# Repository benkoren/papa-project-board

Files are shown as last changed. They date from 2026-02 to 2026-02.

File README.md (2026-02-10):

# papa-project-board

This is a universal controller board, centered around the ESP32-C6-DevkitC-1-N8 development board. It is meant to be a solid jumping off point for microcontroller-oriented projects which justify the beefy features of the C6 devkit, including JTAG, 32-bit RISC-V MCU & 2.4 GHz Wi-Fi 6 & Bluetooth 5 (LE) & IEEE 802.15.4, etc.

(TODO: INSERT YOUTUBE DEMO LINK)

## PCB

This universal controller board in particular includes:
 - 1.3" OLED (which you can swap for other sizes as well)
 - (2) 12mm momentary push-button switches
 - rotary encoder switch
 - active buzzer
 - (2) dedicated connectors for 3-pin sensors (ex: DHT-22)
 - (2) dedicated connectors (and extra capacitance) for driving servo motors
 - TBD62783A chip for driving things like relays while protecting our MCU
 - LM2596T-5 voltage regulator that allows the board to be driven by anywhere between 6 and 45 volts (enabling the use of a wide variety of DC power supplies)
 - 10-pin JST-XH connectors are meant to be the primary interface to the usable GPIO pins of the MCU, though extra header pins are included to facilitate tinkering on the benchtop as well
 - 4-pin JSH-XH connector used to extend the I2C devices beyond the included OLED display

For the particular components & footprints, I chose sizes that are easy to install and maintain over the long-term - all Through Hole Technology (THT) components, and no Surface Mount Device (SMD). Silkscreens were heavily utilized so that the user does not need the schematic to populate and maintain the board - all information needed is printed right on the board.

The PCB design was done in KiCad - all relevant files are located in the `KiCad` folder.

The overall approach and many schematic choices borrow a great deal from the [Banano Board by Electro Bananas](https://www.youtube.com/watch?v=pLuV-ciUMUs) - much gratitude goes to him for his work.

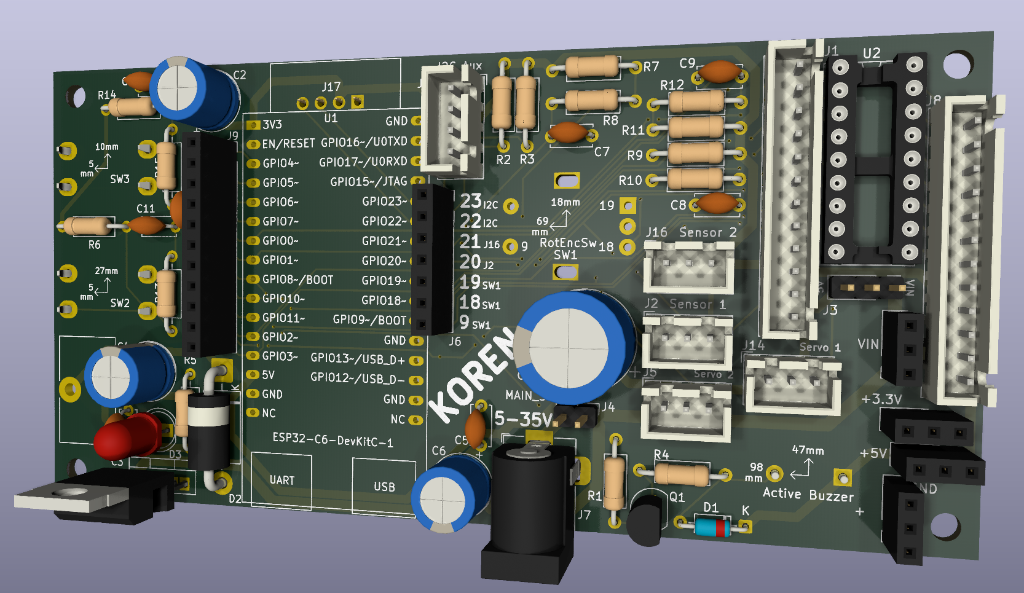
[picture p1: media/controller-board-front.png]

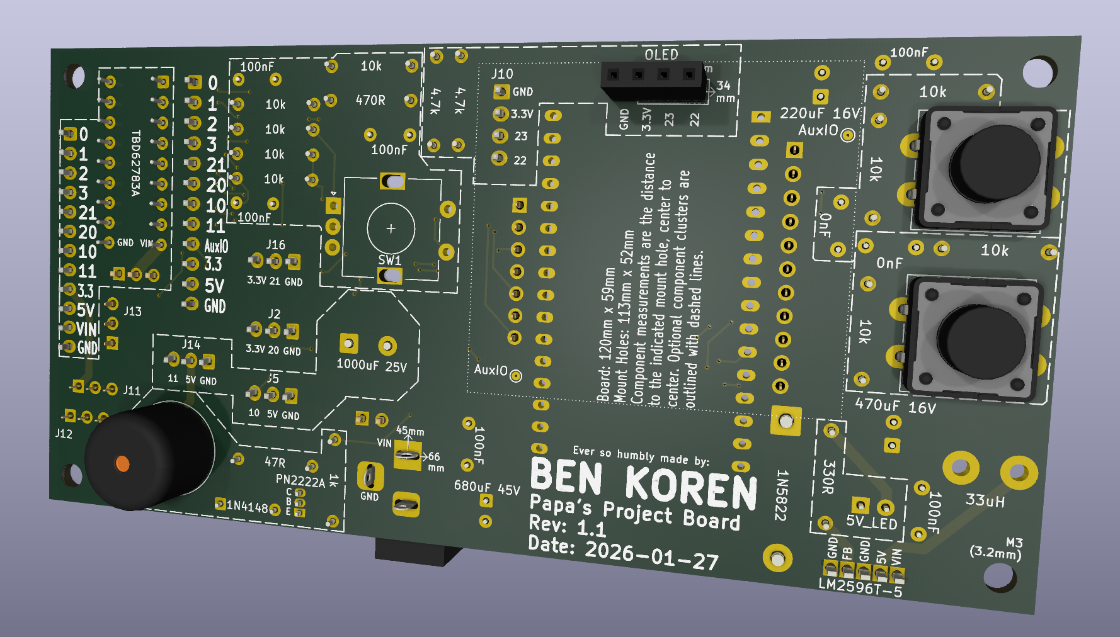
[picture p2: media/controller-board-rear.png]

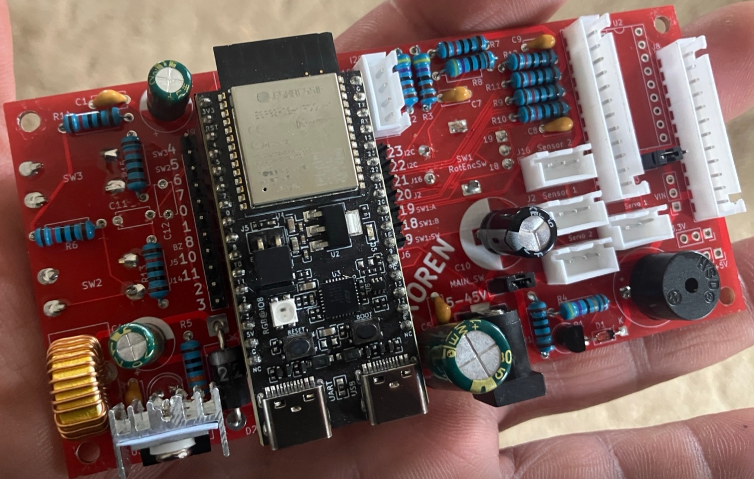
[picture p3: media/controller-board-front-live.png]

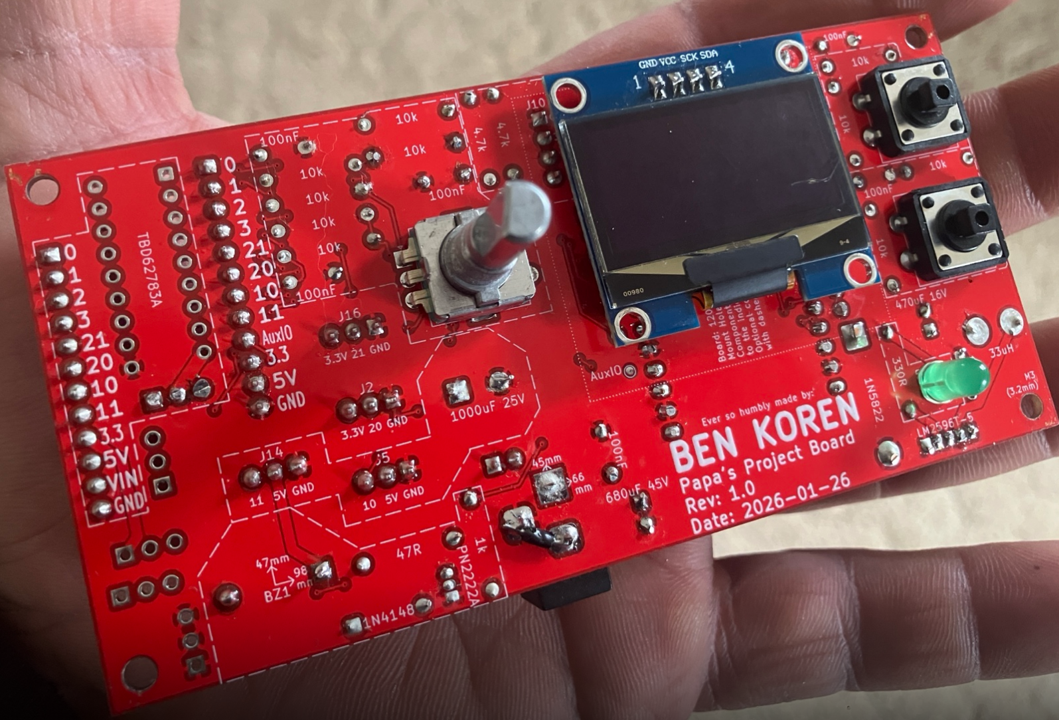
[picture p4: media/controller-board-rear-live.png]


## Enclosure

In addition to the PCB design, I've created a corresponding 3d-printed dashplate which allows the board to be incorporated into any surface mount style application.

One such application is the included "Enclosure Y", which is a small enclosure that orients the input components of the controller board up and toward the user, a rear plate where power supply and other connectors are intended to enter, and a bottom-plate which includes a 20mm grid which allows other components to be secured with included mount trays and M3 bolts.

The enclosure design was done in FreeCAD - all relevant files are located in the `FreeCAD` folder.

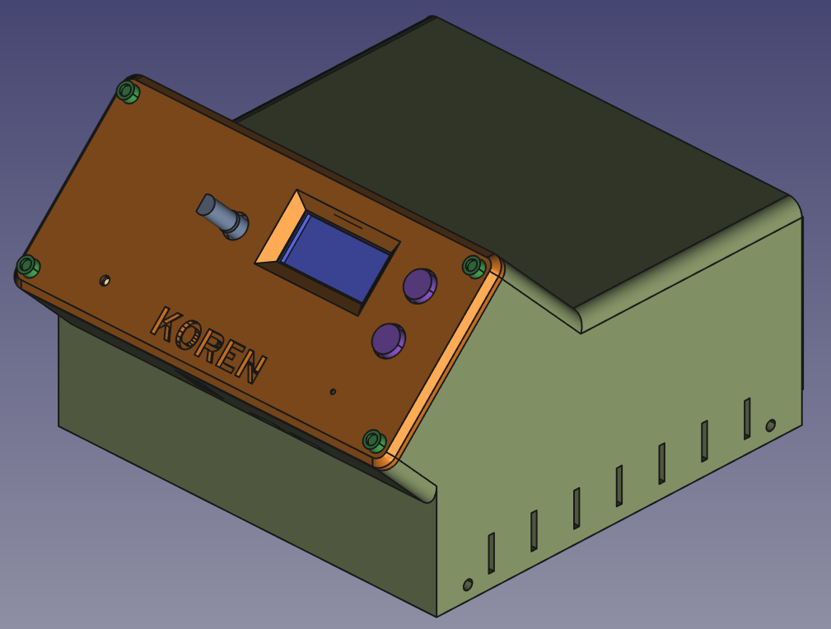
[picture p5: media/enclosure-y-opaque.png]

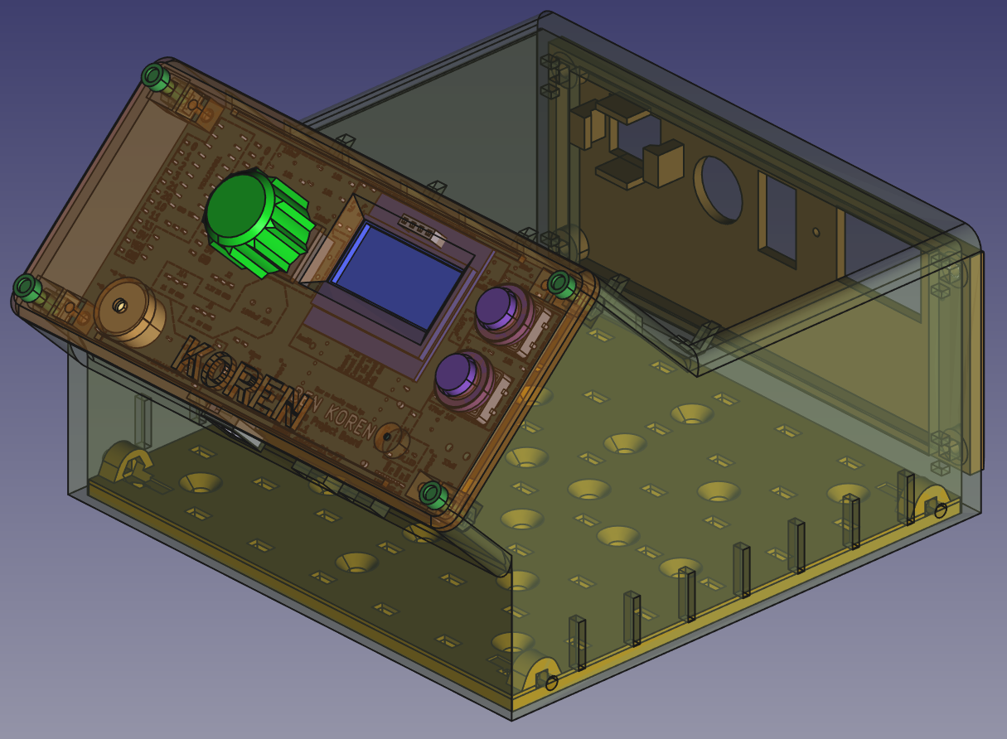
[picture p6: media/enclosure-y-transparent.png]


## Code

Perhaps just as important as the PCB itself is how it's driven: I've created a code template as a great starting point for all projects based upon the universal controller board. It supports some foundational things like driving the OLED and responding to the various inputs included with the board. It's in a separate repository here:

[Papa's Project Board - Code](https://github.com/benkoren/papa-project-board-code)

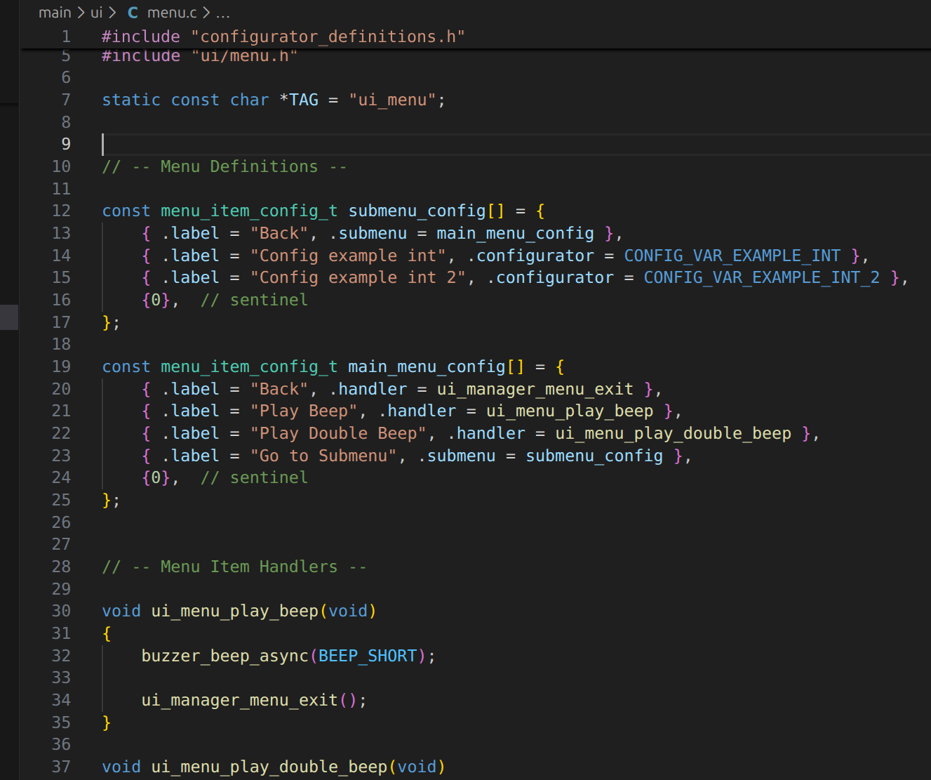
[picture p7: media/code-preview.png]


## Important Changes Across Revisions

### 1.0 to 1.1
 - C11 and C12 are now 0nF - they are counterproductive when using interrupts for SW2 and SW3. We're going to just use software debouncing instead. 
 - R8 is now 470R
 - R5 is now 4.7k (to dim the LED)
 - J7: Both pins 2 and 3 are now connected to GND

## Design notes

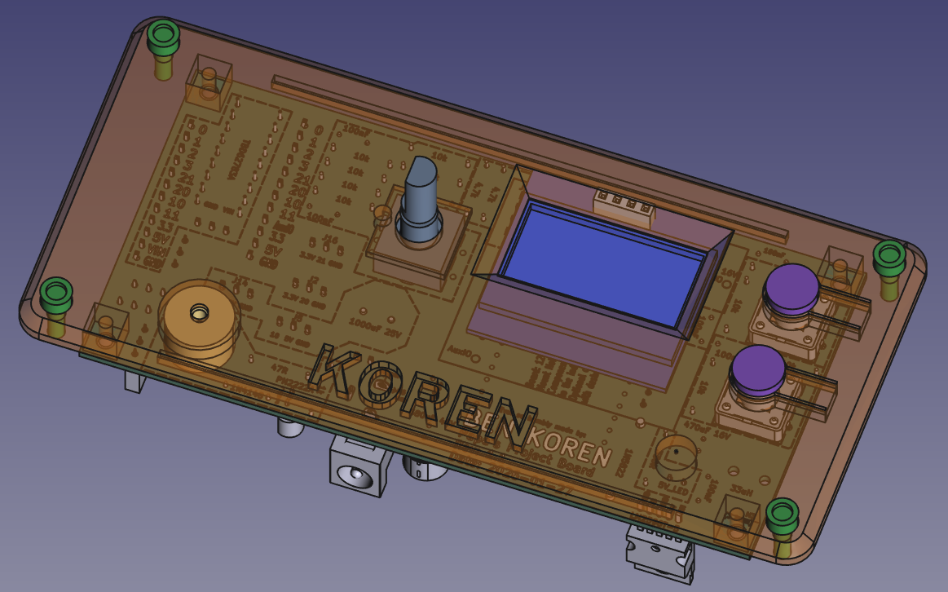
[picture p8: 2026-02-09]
media/dash-plate.png

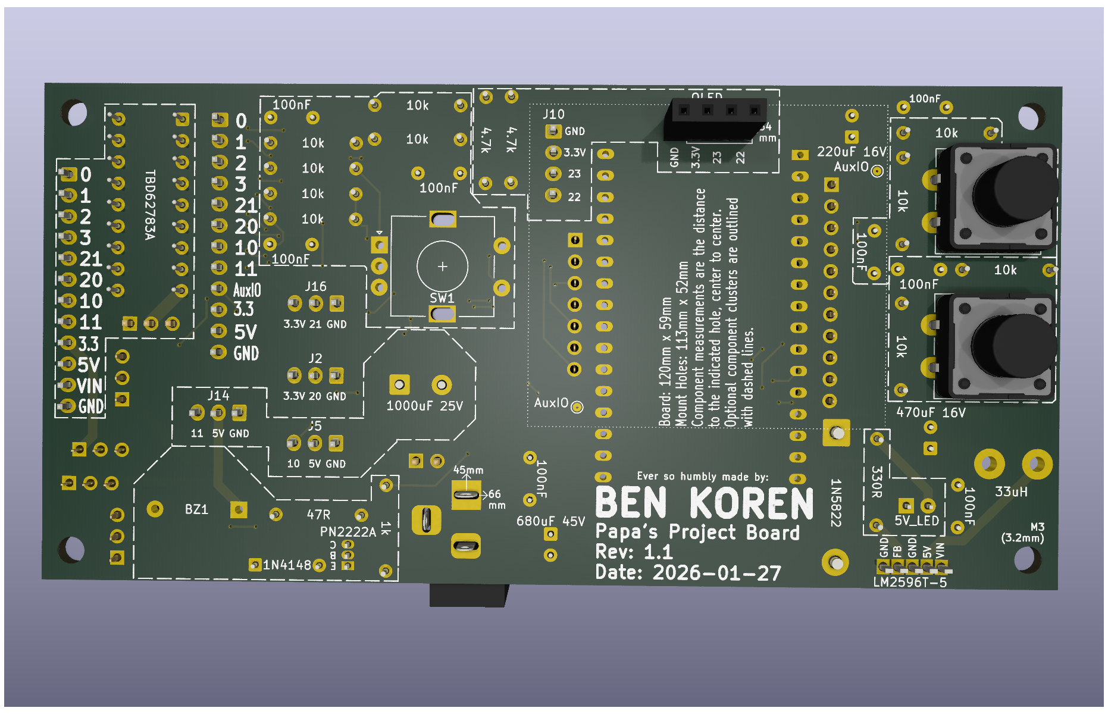
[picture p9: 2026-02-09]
KiCad/Exports/rev1.1/Rear.png

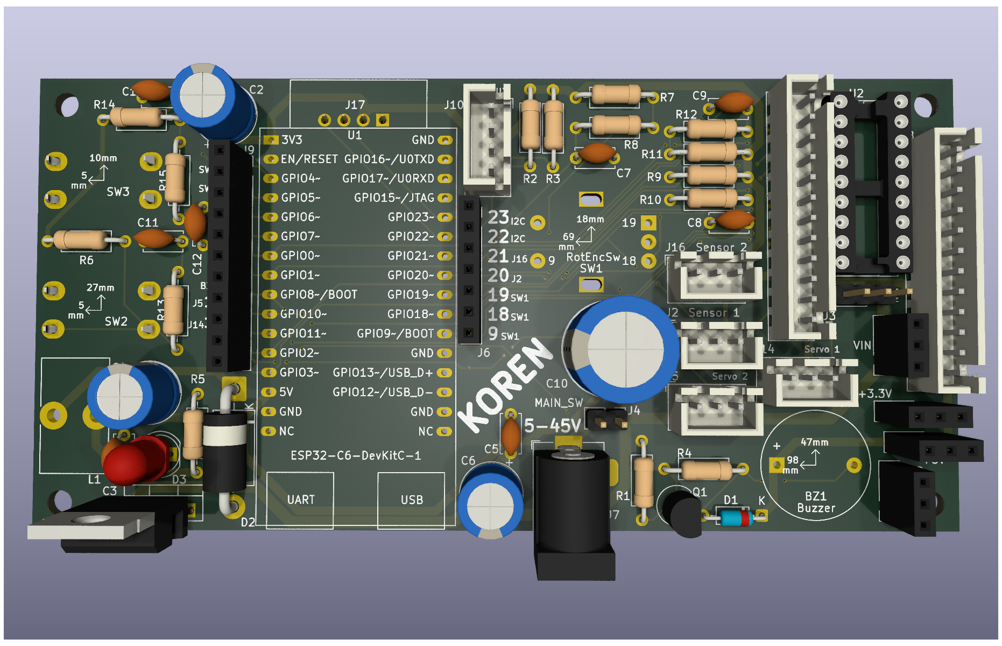
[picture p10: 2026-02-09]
KiCad/Exports/rev1.1/Front.png

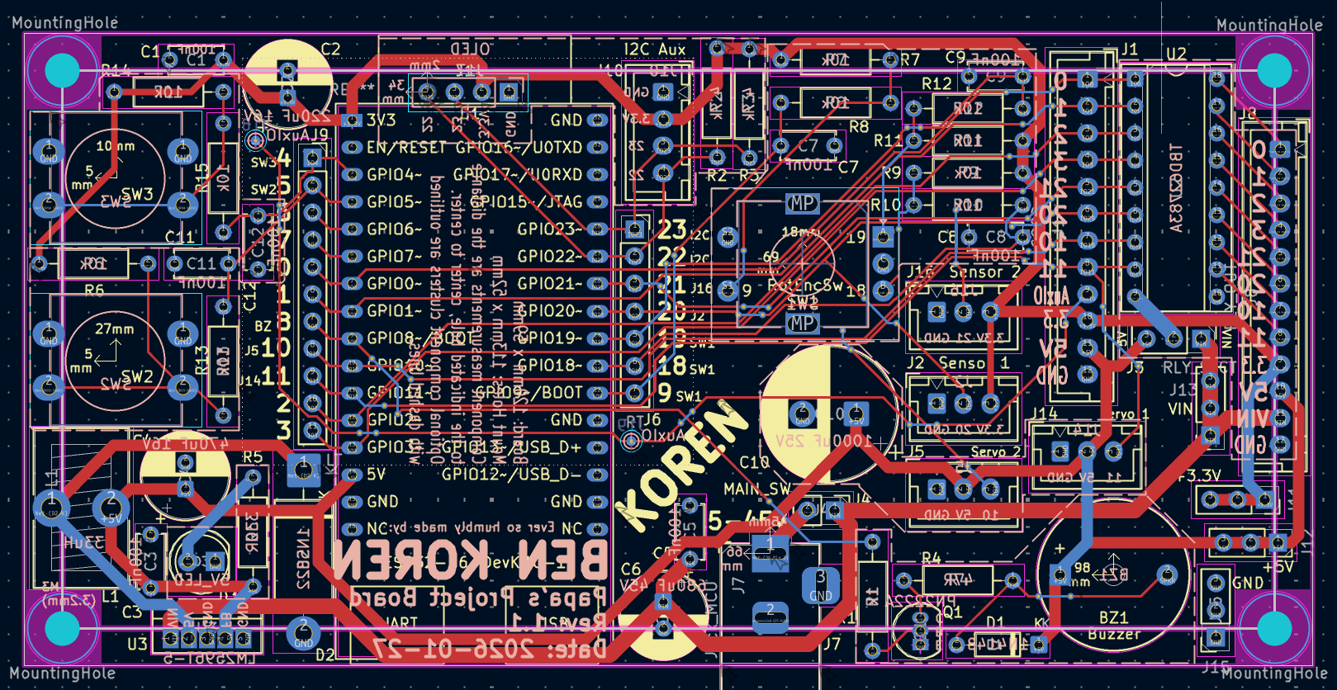
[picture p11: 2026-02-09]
KiCad/Exports/rev1.1/PCB Editor.png

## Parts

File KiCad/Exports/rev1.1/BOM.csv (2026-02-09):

Reference | Qty | Value | DNP | Exclude from BOM | Exclude from Board | Footprint | Datasheet
BZ1 | 1 | Buzzer |  |  |  | Buzzer_Beeper:Buzzer_D14mm_H7mm_P10mm | ~
C1,C3,C5,C7,C8,C9,C11,C12 | 8 | 100nF |  |  |  | Capacitor_THT:C_Disc_D5.0mm_W2.5mm_P5.00mm | ~
C2 | 1 | 220uF 16V |  |  |  | Capacitor_THT:CP_Radial_D8.0mm_P2.50mm | ~
C4 | 1 | 470uF 16V |  |  |  | Capacitor_THT:CP_Radial_D8.0mm_P2.50mm | ~
C6 | 1 | 680uF 45V |  |  |  | Capacitor_THT:CP_Radial_D8.0mm_P2.50mm | ~
C10 | 1 | 1000uF 25V |  |  |  | Capacitor_THT:CP_Radial_D12.5mm_P5.00mm | ~
D1 | 1 | 1N4148 |  |  |  | Diode_THT:D_DO-35_SOD27_P7.62mm_Horizontal | https://assets.nexperia.com/documents/data-sheet/1N4148_1N4448.pdf
D2 | 1 | 1N5822 |  |  |  | Diode_THT:D_DO-201AD_P15.24mm_Horizontal | http://www.vishay.com/docs/88526/1n5820.pdf
D3 | 1 | 5V_LED |  |  |  | LED_THT:LED_D5.0mm | ~
H1,H2,H3,H4 | 4 | MountingHole |  | Excluded from BOM |  | MountingHole:MountingHole_3.2mm_M3 | ~
J1 | 1 | GOOD |  |  |  | Connector_JST:JST_XH_B12B-XH-A_1x12_P2.50mm_Vertical | ~
J2 | 1 | Sensor 1 |  |  |  | Connector_JST:JST_XH_B3B-XH-A_1x03_P2.50mm_Vertical | ~
J3 | 1 | RLY_SLCT |  |  |  | Connector_PinHeader_2.54mm:PinHeader_1x03_P2.54mm_Vertical | ~
J4 | 1 | MAIN_SW |  |  |  | Connector_PinHeader_2.54mm:PinHeader_1x02_P2.54mm_Vertical | ~
J5 | 1 | Servo 2 |  |  |  | Connector_JST:JST_XH_B3B-XH-A_1x03_P2.50mm_Vertical | ~
J6 | 1 | RT |  |  |  | Connector_PinSocket_2.54mm:PinSocket_1x07_P2.54mm_Vertical | ~
J7 | 1 | Jack_MCU |  |  |  | Connector_BarrelJack:BarrelJack_Horizontal | ~
J8 | 1 | RLY_OUT |  |  |  | Connector_JST:JST_XH_B12B-XH-A_1x12_P2.50mm_Vertical | ~
J9 | 1 | LT |  |  |  | Connector_PinSocket_2.54mm:PinSocket_1x11_P2.54mm_Vertical | ~
J10 | 1 | I2C Aux |  |  |  | Connector_JST:JST_XH_B4B-XH-A_1x04_P2.50mm_Vertical | ~
J11 | 1 | +3.3V |  |  |  | Connector_PinSocket_2.54mm:PinSocket_1x03_P2.54mm_Vertical | ~
J12 | 1 | +5V |  |  |  | Connector_PinSocket_2.54mm:PinSocket_1x03_P2.54mm_Vertical | ~
J13 | 1 | VIN |  |  |  | Connector_PinSocket_2.54mm:PinSocket_1x03_P2.54mm_Vertical | ~
J14 | 1 | Servo 1 |  |  |  | Connector_JST:JST_XH_B3B-XH-A_1x03_P2.50mm_Vertical | ~
J15 | 1 | GND |  |  |  | Connector_PinSocket_2.54mm:PinSocket_1x03_P2.54mm_Vertical | ~
J16 | 1 | Sensor 2 |  |  |  | Connector_JST:JST_XH_B3B-XH-A_1x03_P2.50mm_Vertical | ~
J17 | 1 | OLED |  |  |  | Connector_PinSocket_2.54mm:PinSocket_1x04_P2.54mm_Vertical | ~
J18,J19 | 2 | AuxIO |  |  |  | TestPoint:TestPoint_Pad_D1.0mm | ~
L1 | 1 | 33uH |  |  |  | Inductor_THT:L_Toroid_Vertical_L14.7mm_W8.6mm_P5.58mm_Pulse_KM-1 | ~
Q1 | 1 | PN2222A |  |  |  | Package_TO_SOT_THT:TO-92_Inline | https://www.onsemi.com/pub/Collateral/PN2222-D.PDF
R1 | 1 | 1k |  |  |  | Resistor_THT:R_Axial_DIN0207_L6.3mm_D2.5mm_P10.16mm_Horizontal | ~
R2,R3 | 2 | 4.7k |  |  |  | Resistor_THT:R_Axial_DIN0207_L6.3mm_D2.5mm_P10.16mm_Horizontal | ~
R4 | 1 | 47R |  |  |  | Resistor_THT:R_Axial_DIN0207_L6.3mm_D2.5mm_P10.16mm_Horizontal | ~
R5 | 1 | 330R |  |  |  | Resistor_THT:R_Axial_DIN0207_L6.3mm_D2.5mm_P10.16mm_Horizontal | ~
R6,R7,R8,R9,R10,R11,R12,R13,R14,R15 | 10 | 10k |  |  |  | Resistor_THT:R_Axial_DIN0207_L6.3mm_D2.5mm_P10.16mm_Horizontal | ~
SW1 | 1 | RotEncSw |  |  |  | Rotary_Encoder:RotaryEncoder_Alps_EC11E-Switch_Vertical_H20mm | ~
SW2 | 1 | SW_IO5 |  |  |  | Button_Switch_THT:SW_PUSH-12mm_Wuerth-430476085716 | ~
SW3 | 1 | SW_IO8 |  |  |  | Button_Switch_THT:SW_PUSH-12mm_Wuerth-430476085716 | ~
U1 | 1 | ESP32-C6-DevKitC-1 |  |  |  | PCM_Espressif:ESP32-C6-DevKitC-1 | https://docs.espressif.com/projects/espressif-esp-dev-kits/en/latest/esp32c6/esp32-c6-devkitc-1/user_guide.html
U2 | 1 | TBD62783A |  |  |  | Package_DIP:DIP-18_W7.62mm_Socket | http://toshiba.semicon-storage.com/info/docget.jsp?did=30523&prodName=TBD62783APG
U3 | 1 | LM2596T-5 |  |  |  | Package_TO_SOT_THT:TO-220-5_Vertical | http://www.ti.com/lit/ds/symlink/lm2596.pdf

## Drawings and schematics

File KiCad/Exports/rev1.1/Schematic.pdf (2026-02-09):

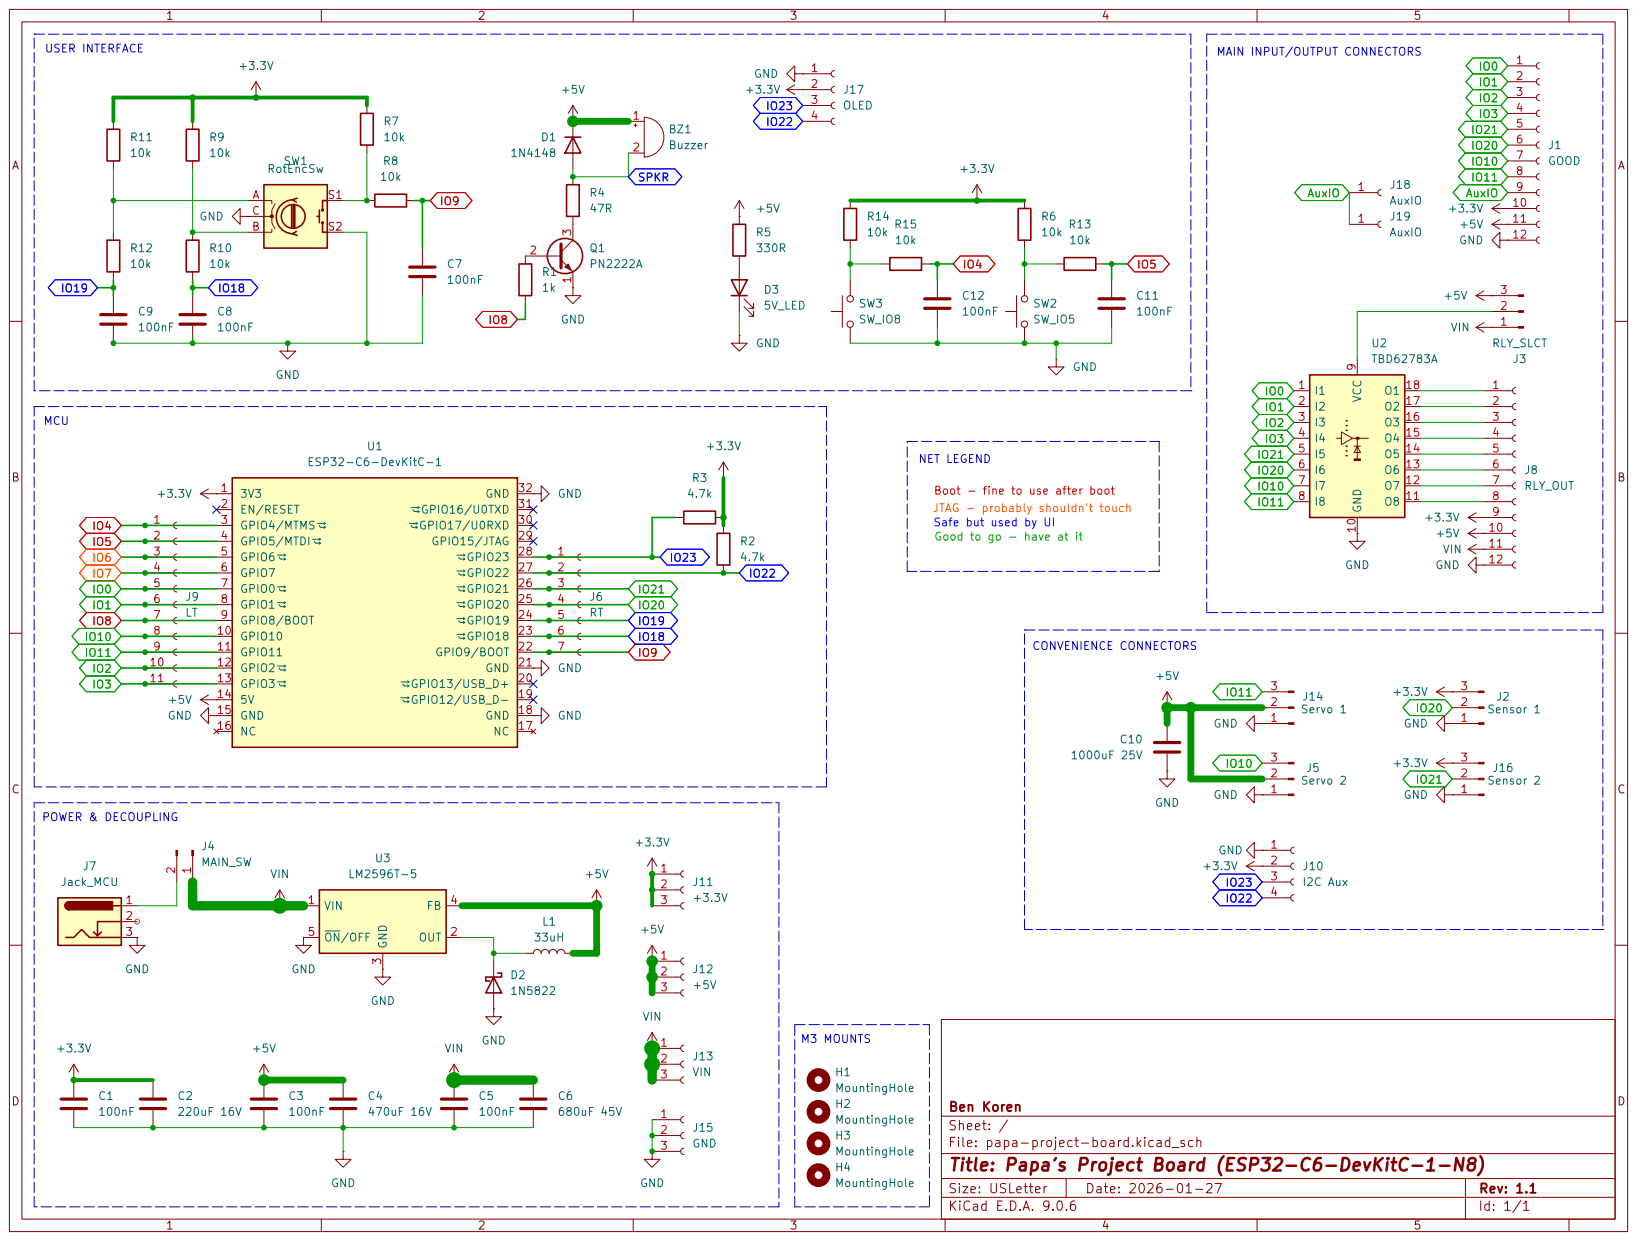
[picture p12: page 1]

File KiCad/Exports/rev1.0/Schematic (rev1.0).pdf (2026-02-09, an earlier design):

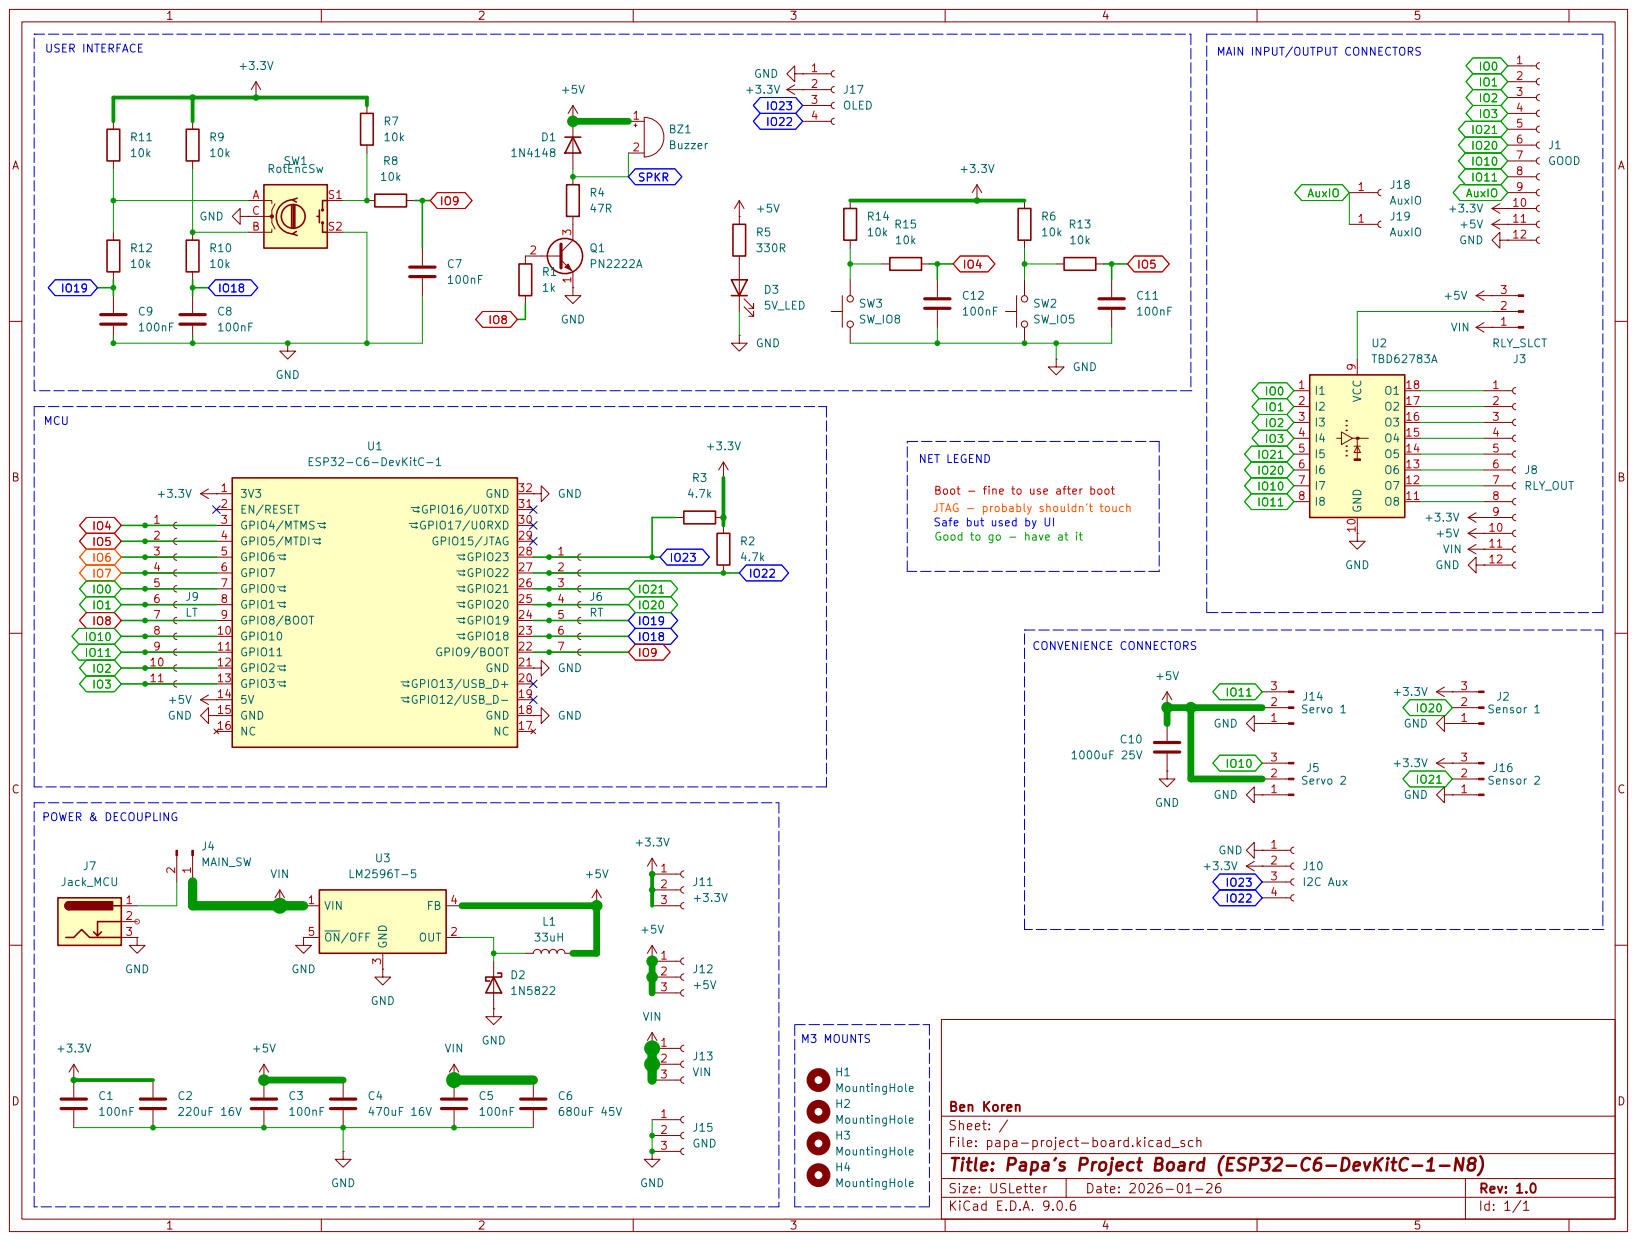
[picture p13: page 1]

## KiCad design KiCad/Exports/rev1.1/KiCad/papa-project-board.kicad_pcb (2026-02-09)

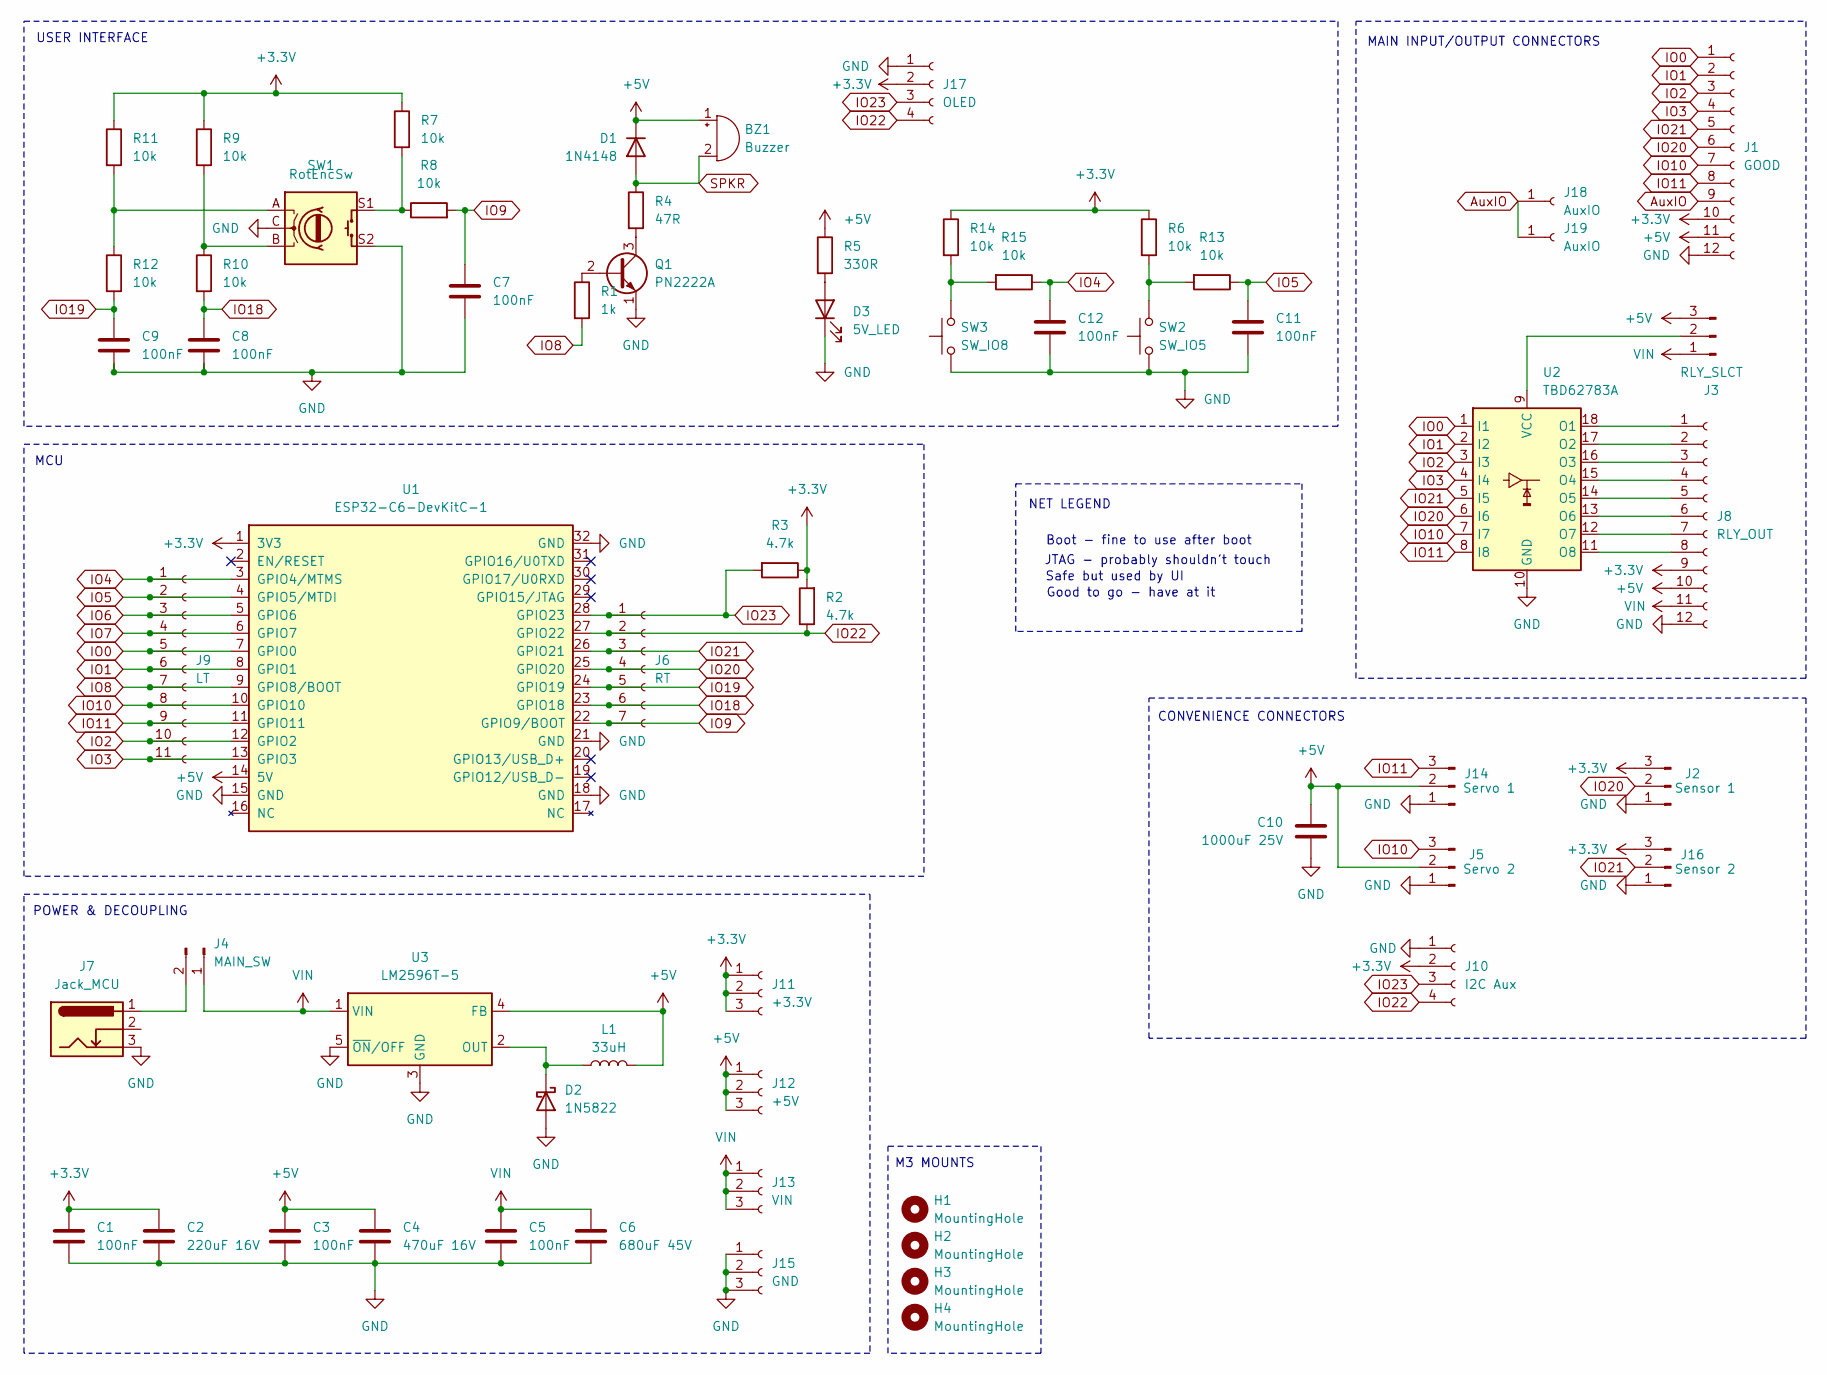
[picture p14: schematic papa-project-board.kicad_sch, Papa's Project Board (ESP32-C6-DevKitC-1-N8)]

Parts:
BZ1: Buzzer; Buzzer_D14mm_H7mm_P10mm
C1, C3, C5, C7, C8, C9, C11, C12: 100nF; C_Disc_D5.0mm_W2.5mm_P5.00mm
C2: 220uF 16V; CP_Radial_D8.0mm_P2.50mm
C4: 470uF 16V; CP_Radial_D8.0mm_P2.50mm
C6: 680uF 45V; CP_Radial_D8.0mm_P2.50mm
C10: 1000uF 25V; CP_Radial_D12.5mm_P5.00mm
D1: 1N4148; D_DO-35_SOD27_P7.62mm_Horizontal
D2: 1N5822; D_DO-201AD_P15.24mm_Horizontal
D3: 5V_LED; LED_D5.0mm
H1, H2, H3, H4: MountingHole; MountingHole_3.2mm_M3
J1: GOOD; JST_XH_B12B-XH-A_1x12_P2.50mm_Vertical
J2: Sensor 1; JST_XH_B3B-XH-A_1x03_P2.50mm_Vertical
J3: RLY_SLCT; PinHeader_1x03_P2.54mm_Vertical
J4: MAIN_SW; PinHeader_1x02_P2.54mm_Vertical
J5: Servo 2; JST_XH_B3B-XH-A_1x03_P2.50mm_Vertical
J6: RT; PinSocket_1x07_P2.54mm_Vertical
J7: Jack_MCU; BarrelJack_Horizontal
J8: RLY_OUT; JST_XH_B12B-XH-A_1x12_P2.50mm_Vertical
J9: LT; PinSocket_1x11_P2.54mm_Vertical
J10: I2C Aux; JST_XH_B4B-XH-A_1x04_P2.50mm_Vertical
J11: +3.3V; PinSocket_1x03_P2.54mm_Vertical
J12: +5V; PinSocket_1x03_P2.54mm_Vertical
J13: VIN; PinSocket_1x03_P2.54mm_Vertical
J14: Servo 1; JST_XH_B3B-XH-A_1x03_P2.50mm_Vertical
J15: GND; PinSocket_1x03_P2.54mm_Vertical
J16: Sensor 2; JST_XH_B3B-XH-A_1x03_P2.50mm_Vertical
J17: OLED; PinSocket_1x04_P2.54mm_Vertical
J18, J19: AuxIO; TestPoint_Pad_D1.0mm
L1: 33uH; L_Toroid_Vertical_L14.7mm_W8.6mm_P5.58mm_Pulse_KM-1
Q1: PN2222A; TO-92_Inline
R1: 1k; R_Axial_DIN0207_L6.3mm_D2.5mm_P10.16mm_Horizontal
R2, R3: 4.7k; R_Axial_DIN0207_L6.3mm_D2.5mm_P10.16mm_Horizontal
R4: 47R; R_Axial_DIN0207_L6.3mm_D2.5mm_P10.16mm_Horizontal
R5: 330R; R_Axial_DIN0207_L6.3mm_D2.5mm_P10.16mm_Horizontal
R6, R7, R8, R9, R10, R11, R12, R13, R14, R15: 10k; R_Axial_DIN0207_L6.3mm_D2.5mm_P10.16mm_Horizontal
SW1: RotEncSw; RotaryEncoder_Alps_EC11E-Switch_Vertical_H20mm
SW2: SW_IO5; SW_PUSH-12mm_Wuerth-430476085716
SW3: SW_IO8; SW_PUSH-12mm_Wuerth-430476085716
U1: ESP32-C6-DevKitC-1
U2: TBD62783A; DIP-18_W7.62mm_Socket
U3: LM2596T-5; TO-220-5_Vertical

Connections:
+3.3V: C1.1, C2.1, J1.10, J2.3, J8.9, J10.2, J11.1, J11.2, J11.3, J16.3, J17.2, R2.2, R3.1, R6.1, R7.1, R9.1, R11.1, R14.1, U1.1 (3V3)
+5V: BZ1.1 (+), C3.1, C4.1, C10.1, D1.1 (K), J1.11, J3.3, J5.2, J8.10, J12.1, J12.2, J12.3, J14.2, L1.2, R5.1, U1.14 (5V), U3.4 (FB)
AuxIO: J1.9, J18.1, J19.1
GND: C1.2, C2.2, C3.2, C4.2, C5.2, C6.2, C7.2, C8.2, C9.2, C10.2, C11.2, C12.2, D2.2 (A), D3.1 (K), J1.12, J2.1, J5.1, J7.3, J8.12, J10.1, J14.1, J15.1, J15.2, J15.3, J16.1, J17.1, Q1.1 (E), SW1.C, SW1.S2, SW2.1, SW3.1, U1.15 (GND), U1.18 (GND), U1.21 (GND), U1.32 (GND), U2.10 (GND), U3.3 (GND), U3.5 (~ON/OFF)
IO0: J1.1, J9.5, U1.7 (GPIO0), U2.1 (I1)
IO1: J1.2, J9.6, U1.8 (GPIO1), U2.2 (I2)
IO2: J1.3, J9.10, U1.12 (GPIO2), U2.3 (I3)
IO3: J1.4, J9.11, U1.13 (GPIO3), U2.4 (I4)
IO4: C12.1, J9.1, R15.1, U1.3 (GPIO4/MTMS)
IO5: C11.1, J9.2, R13.1, U1.4 (GPIO5/MTDI)
IO6: J9.3, U1.5 (GPIO6)
IO7: J9.4, U1.6 (GPIO7)
IO8: J9.7, R1.2, U1.9 (GPIO8/BOOT)
IO9: C7.1, J6.7, R8.2, U1.22 (GPIO9/BOOT)
IO10: J1.7, J5.3, J9.8, U1.10 (GPIO10), U2.7 (I7)
IO11: J1.8, J9.9, J14.3, U1.11 (GPIO11), U2.8 (I8)
IO18: C8.1, J6.6, R10.2, U1.23 (GPIO18)
IO19: C9.1, J6.5, R12.2, U1.24 (GPIO19)
IO20: J1.6, J2.2, J6.4, U1.25 (GPIO20), U2.6 (I6)
IO21: J1.5, J6.3, J16.2, U1.26 (GPIO21), U2.5 (I5)
IO22: J6.2, J10.4, J17.4, R2.1, U1.27 (GPIO22)
IO23: J6.1, J10.3, J17.3, R3.2, U1.28 (GPIO23)
unnamed: D2.1 (K), L1.1, U3.2 (OUT)
unnamed: D3.2 (A), R5.2
unnamed: J3.2, U2.9 (VCC)
unnamed: J4.2, J7.1
unnamed: J8.1, U2.18 (O1)
unnamed: J8.2, U2.17 (O2)
unnamed: J8.3, U2.16 (O3)
unnamed: J8.4, U2.15 (O4)
unnamed: J8.5, U2.14 (O5)
unnamed: J8.6, U2.13 (O6)
unnamed: J8.7, U2.12 (O7)
unnamed: J8.8, U2.11 (O8)
unnamed: Q1.2 (B), R1.1
unnamed: Q1.3 (C), R4.2
unnamed: R7.2, R8.1, SW1.S1
unnamed: R9.2, R10.1, SW1.B
unnamed: R11.2, R12.1, SW1.A
unnamed: R6.2, R13.2, SW2.2
unnamed: R14.2, R15.2, SW3.2
SPKR: BZ1.2 (-), D1.2 (A), R4.1
VIN: C5.1, C6.1, J3.1, J4.1, J8.11, J13.1, J13.2, J13.3, U3.1 (VIN)

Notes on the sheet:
JTAG - probably shouldn't touch
USER INTERFACE
Boot - fine to use after boot
Good to go - have at it
MAIN INPUT/OUTPUT CONNECTORS
MCU
M3 MOUNTS
Safe but used by UI
NET LEGEND
POWER & DECOUPLING
CONVENIENCE CONNECTORS

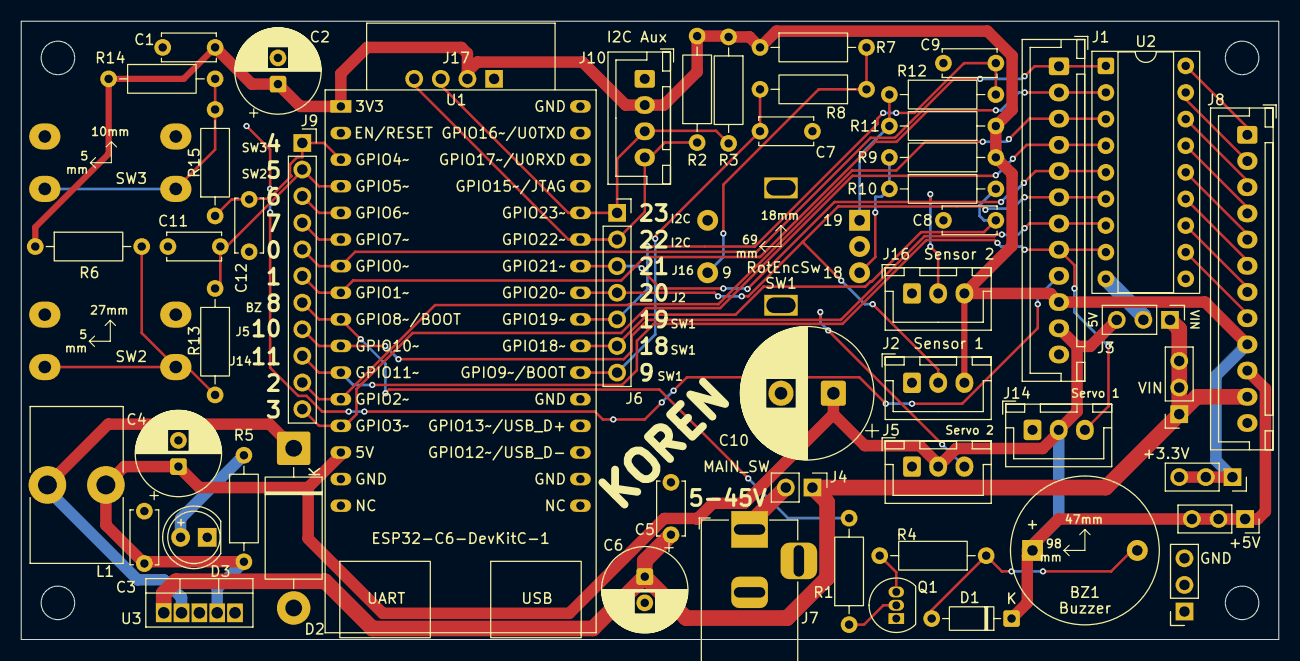
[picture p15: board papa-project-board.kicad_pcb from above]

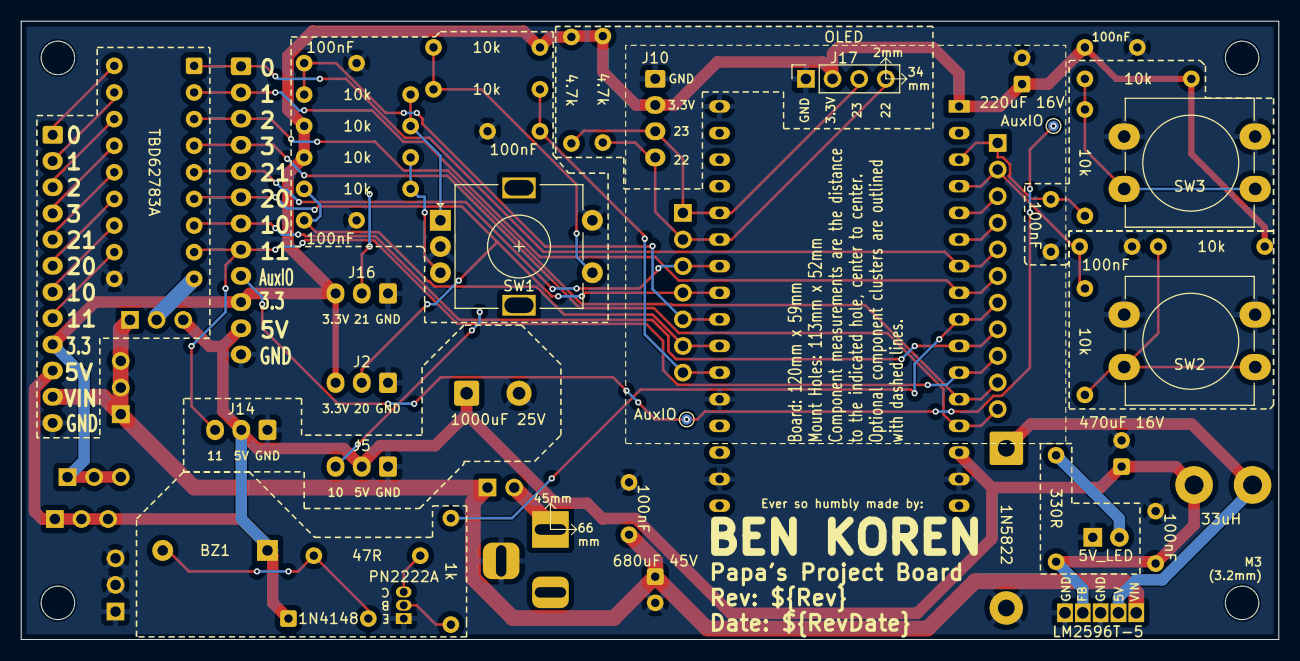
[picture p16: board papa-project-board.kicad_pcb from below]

Board: 2 copper layers, 120.0 x 59.0 mm, 62 parts (6 on the bottom side), 43 nets.

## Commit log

2026-02-10 Dimmed the power LED
    [papa-project-board.kicad_pcb, papa-project-board.kicad_sch]
2026-02-12 Increased size of Y enclosure, changed button facade style
2026-02-19 Beefed up the rear plate
2026-02-19 Moved bottom plate mount bolts to the sides
2026-02-24 Fixed enclosure mount nut pockets
2026-02-24 Enclosure Y: bottom plate now rests within main body
